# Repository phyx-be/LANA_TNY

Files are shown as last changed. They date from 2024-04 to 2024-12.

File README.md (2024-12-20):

# LANA TNY
## LANA
LANA is a small development board based around the [WCH CH32V203G6U6](https://www.wch-ic.com/products/CH32V203.html) RISC-V microcontroller. 

## CH32V203
Our initial development was made using the G8U6 variant of this microcontroller featuring more RAM, however by the time we finished the design the chip was no longer available in this small package with the larger RAM size. Therfore we settled for the CH32V203G6U6.
The CH32V203G6 has a single 32-bit RISC-V core, running up to 144MHz, with 1-cycle multiply, and hardware divide. Inside is **10KB** SRAM, **32KB** single-cycle Flash as well as an additional 'external XIP' **224KB** of Flash that can be used for program or data storage but is not as fast as the 32KB. There's also extras you expect: ADC, timers, USB device, UART, I2C, CAN, touch and SPI. 

## Where can I get one?
Currently you can get your hands on the LANA_TNY [in our Lectronz store](https://lectronz.com/products/lana-tny) or [through Adafruit](https://www.adafruit.com/product/6042).

## Programming

### Writing code
Various options are available.
- [Embeetle](https://embeetle.com/)
	- [Officially supported by Embeetle](https://embeetle.com/#supported-hardware/wch/boards/lana-tny-01)
- [Arduino core](https://github.com/openwch/arduino_core_ch32)
	- SPI and I²C Master support since version 1.0.2
- [Platform.io](https://github.com/Community-PIO-CH32V/platform-ch32v)
	- Requires your WCH-Link firmware to be updated to the latest version
- [CH32V003fun](https://github.com/cnlohr/ch32v003fun)
	- Experimental support for the CH32V203 at the time of writing
- [MounRiver Studio](https://www.mounriver.com/)
	- The official IDE supported by WCH, based on Eclipse.
- [WCH Toolchain for Mac](https://github.com/robinjanssens/WCH-Toolchain)
	- This toolchain has official support for LANA

### Loading code
The CH32V203 has an USB Bootloader which can be activated by holding down the button when plugging in the USB cable. Alternatively you could opt to use a [WCH-Link programmer and debugger](https://www.wch.cn/products/WCH-Link.html) to connect to the exposed SWD pins.

## TNY ?
TNY is our take on the [Adafruit QT Py](https://www.adafruit.com/category/595) and [Seeed studio XIAO](https://wiki.seeedstudio.com/Seeeduino-XIAO/) specifications but with added SMD pins for optional extra IO capabilities and a built in WS2811 compatible LED output.

## Pinout
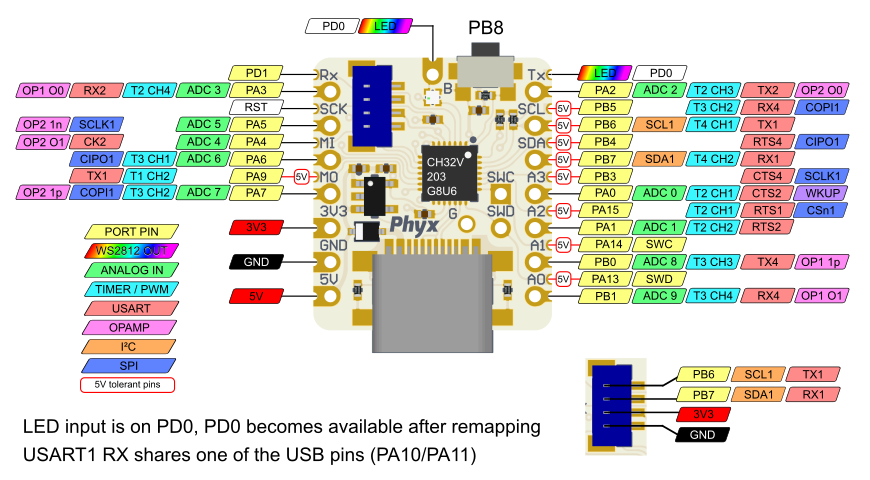
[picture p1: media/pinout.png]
LANA TNY 01 pinout


## LANA REV 01
LANA TNY 01 LED

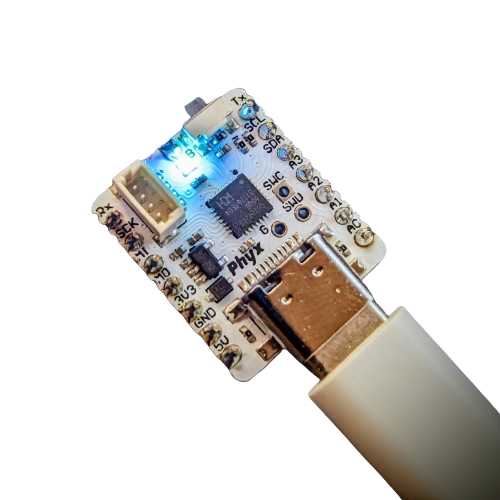
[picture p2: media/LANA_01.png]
LANA TNY 01


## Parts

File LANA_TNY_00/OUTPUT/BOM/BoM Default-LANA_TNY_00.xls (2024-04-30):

Bill of Materials |  |  | Lana Tny
Project: |  | LANA_TNY_00.PrjPcb
Revision: |  | 00
Variant: |  | Default
Creation Date: | 31/08/2023 | 09:10
Print Date: | 2023-09-01 | 14:35:48
Footprint | Comment | LibRef | Designator | Value | Description | Supplier 1 | Supplier PN 1 | Quantity | Quantity 500 | €500 | €1000
C0402 |  | CAP # 100nF 16V 0402 | C1, C2, C7 | 100nF 16V | CAP # 100nF 16V 0402 | LCSC | C392963 | 3 | 1500 | 1.05 | 1.8
C0402 |  | CAP # 1uF 10V 0402 | C3, C4 | 1uF 10V | CAP # 1uF 10V 0402 | LCSC | C380293 | 2 | 1000 | 1.4 | 2.8
LED_1010_WS2812B | WS2812 based digital RGB LED 1010 package | LED # RGB XL-1010RGBC-WS2812B | D1 | XL-1010RGBC-WS2812B | LED # RGB XL-1010RGBC-WS2812B | LCSC | C5349953 | 1 | 500 | 18.4 | 32.9
SOD-323_AC | CUS10S30 Schottky Power Rectifier, 1A, 30V | Schottky # CUS10S30 | D2 | CUS10S30,H3F | Schottky # CUS10S30 | LCSC | C146335 | 1 | 500 | 12.35 | 24.7
XUNPU-TYPEC-304S-ACP16 | USB 2.0 C Reversible Receptacle Horizontal full SMD | USB # C 2.0 RCPT TYPEC-304S-ACP16 | J1 | TYPEC-304S-ACP16 | USB # C 2.0 RCPT TYPEC-304S-ACP16 | LCSC | C5187472 | 1 | 500 | 21.75 | 37.4
WE_665304124022 | Header 1.0mm Shrouded 4 | HDR # SHR 1.0mm 4way - 665304124022 | P3 | 665304124022 | HDR # SHR 1.0mm 4way - 665304124022 | LCSC | C7433440 | 1 | 500 | 7.5 | 14.6
R0402 |  | RES # 5K1 0402 | R1, R2, R3, R4, R5 | 5K1 | RES # 5K1 0402 | LCSC | C274895 | 5 | 2500 | 1.5 | 2.5
SHOU_HAN_TS24CA | TS24CA RA Tactile Switch 12V 50mA | SW # TACT RA TS24CA | SW2 | TS24CA | SW # TACT RA TS24CA | LCSC | C393942 | 1 | 500 | 7.65 | 13
QFN_28_4.0x4.0_P0.4 | WCH CH32V203G8U6 QFN28 RISC-V 32-bit MCU, 64KB Flash, 20KB RAM, USB, CAN | RISCV # CH32V203G8U6 | U1 | CH32V203G8U6 | RISCV # CH32V203G8U6 | LCSC | C5187530 | 1 | 500 | 173.05 | 338.8
SOT23-5 | 3V3 LDO 300mA 150mV | LDO # 3V3 300mA RT9078-33GJ5 | U2 | RT9078-33GJ5 | LDO # 3V3 300mA RT9078-33GJ5 | LCSC | C110427 | 1 | 500 | 27.05 | 54.1
 |  |  |  |  |  |  |  | 17 |  | €271.70 | €522.60
Approved |  | Notes
 |  |  |  |  |  |  |  |  |  | €0.5434 | €0.5226

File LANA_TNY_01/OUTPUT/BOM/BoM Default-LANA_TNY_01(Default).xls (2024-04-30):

Bill of Materials |  |  | Lana Tny
Project: |  | LANA_TNY_01.PrjPcb
Revision: |  | 01
Variant: |  | Default
Creation Date: | 12/11/2023 | 20:50
Print Date: | 2024-04-12 | 10:24:27
Footprint | Comment | LibRef | Designator | Value | Description | Supplier 1 | Supplier Part Number 1 | Supplier 2 | Supplier Part Number 2 | Supplier 3 | Supplier Part Number 3 | Quantity
C0402 |  | CAP # 100nF 16V 0402 | C1, C2, C7 | 100nF 16V | CAP # 100nF 16V 0402 | Farnell | 1758896 | LCSC | C392963 | Generic | 100nF 16V 0402 X7R | 3
C0402 |  | CAP # 1uF 10V 0402 | C3, C4 | 1uF 10V | CAP # 1uF 10V 0402 | LCSC | C380293 |  |  | Generic | 1uF 10V 0402 X5R | 2
LED_1010_WS2812B | WS2812 based digital RGB LED 1010 package | LED # RGB XL-1010RGBC-WS2812B | D1 | XL-1010RGBC-WS2812B | LED # RGB XL-1010RGBC-WS2812B | LCSC | C5349953 |  |  |  |  | 1
SOD-323_AC | CUS10S30 Schottky Power Rectifier, 1A, 30V | Schottky # CUS10S30 | D2 | CUS10S30,H3F | Schottky # CUS10S30 | LCSC | C146335 |  |  |  |  | 1
XUNPU-TYPEC-304S-ACP16 | USB 2.0 C Reversible Receptacle Horizontal full SMD | USB # C 2.0 RCPT TYPEC-304S-ACP16 | J1 | TYPEC-304S-ACP16 | USB # C 2.0 RCPT TYPEC-304S-ACP16 | LCSC | C5187472 | LCSC | C2927040 | LCSC | C5156603 | 1
WE_665304124022 | Header 1.0mm Shrouded 4 | HDR # SHR 1.0mm 4way - 665304124022 | P3 | 665304124022 | HDR # SHR 1.0mm 4way - 665304124022 | Wurth | 665304124022 | Mouser | 710-665304124022 |  |  | 1
R0402 |  | RES # 5K1 0402 | R1, R2, R3, R4, R5 | 5K1 | RES # 5K1 0402 | LCSC | C274895 |  |  | Generic | 5K1 1% 0402 | 5
SHOU_HAN_TS24CA | TS24CA RA Tactile Switch 12V 50mA | SW # TACT RA TS24CA | SW2 | TS24CA | SW # TACT RA TS24CA | LCSC | C393942 |  |  |  |  | 1
QFN_28_4.0x4.0_P0.4 | WCH CH32V203G8U6 QFN28 RISC-V 32-bit MCU, 64KB Flash, 20KB RAM, USB, CAN | RISCV # CH32V203G8U6 | U1 | CH32V203G8U6 | RISCV # CH32V203G8U6 | LCSC | C5187530 |  |  |  |  | 1
SOT23-5 | 3V3 LDO 300mA 150mV | LDO # 3V3 300mA RT9078-33GJ5 | U2 | RT9078-33GJ5 | LDO # 3V3 300mA RT9078-33GJ5 | LCSC | C110427 |  |  |  |  | 1
 |  |  |  |  |  |  |  |  |  |  |  | 17
Approved |  | Notes

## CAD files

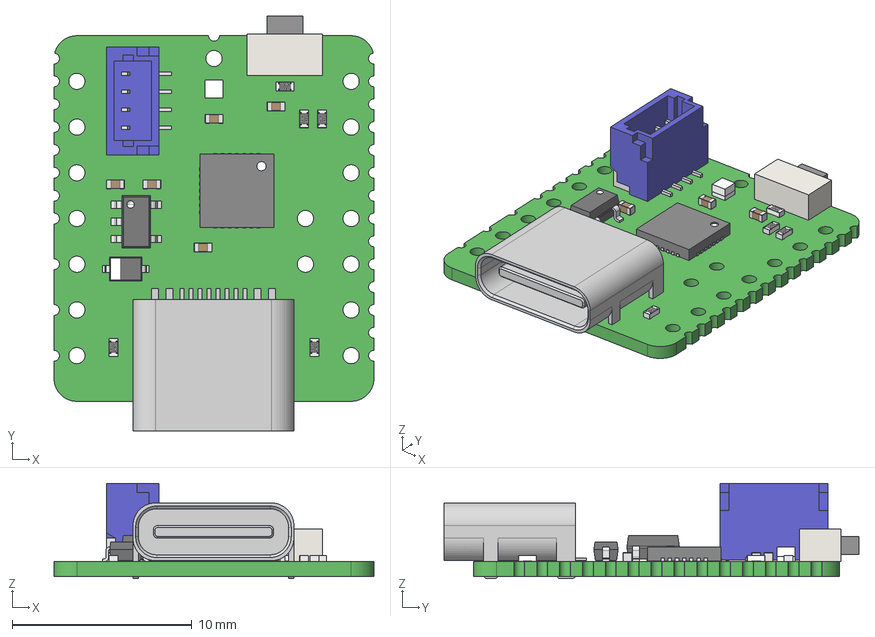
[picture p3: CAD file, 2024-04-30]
LANA_TNY_00/LANA_TNY_00.step
17.8 x 23.0 x 5.30 mm
R0402 x 5
BM04B-SRSS-TB
C0402 x 5
Extruded x 5
User Library-SOT23-5-2
User Library-SOD323-1
Thermal Shape
HRO TYPE-C-31-M-12

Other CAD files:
LANA_TNY_01/LANA_TNY_01.step

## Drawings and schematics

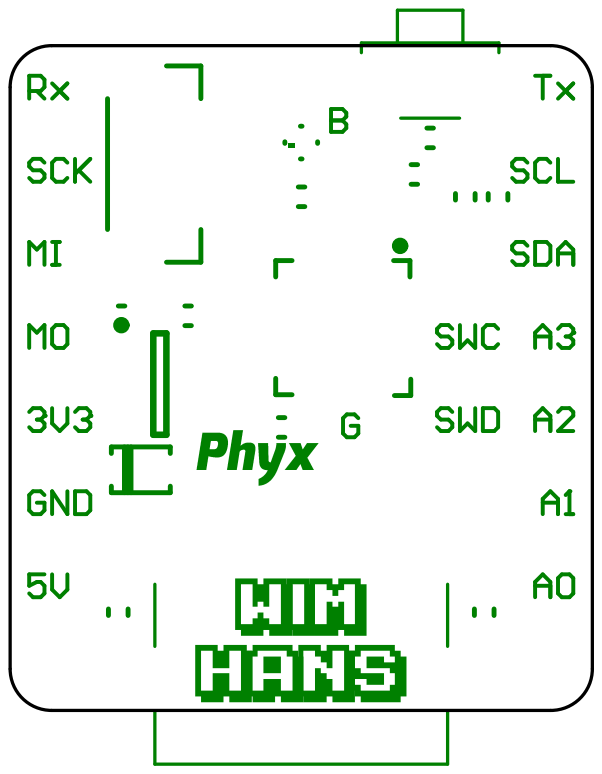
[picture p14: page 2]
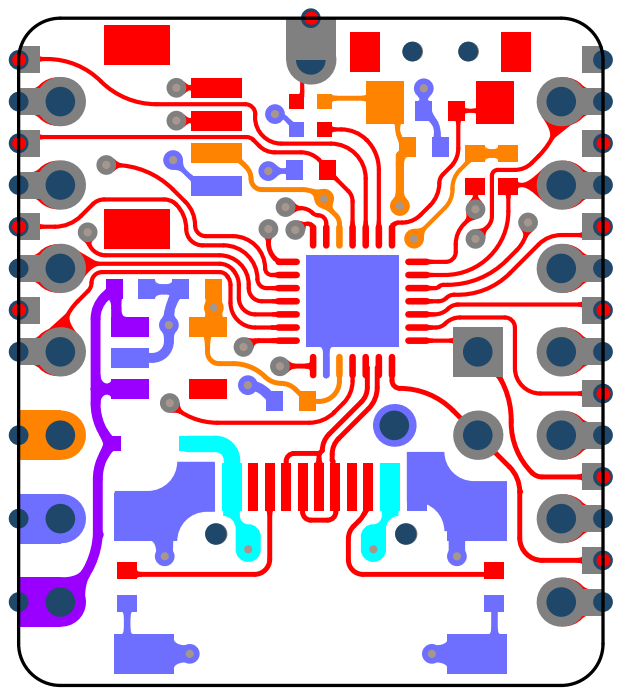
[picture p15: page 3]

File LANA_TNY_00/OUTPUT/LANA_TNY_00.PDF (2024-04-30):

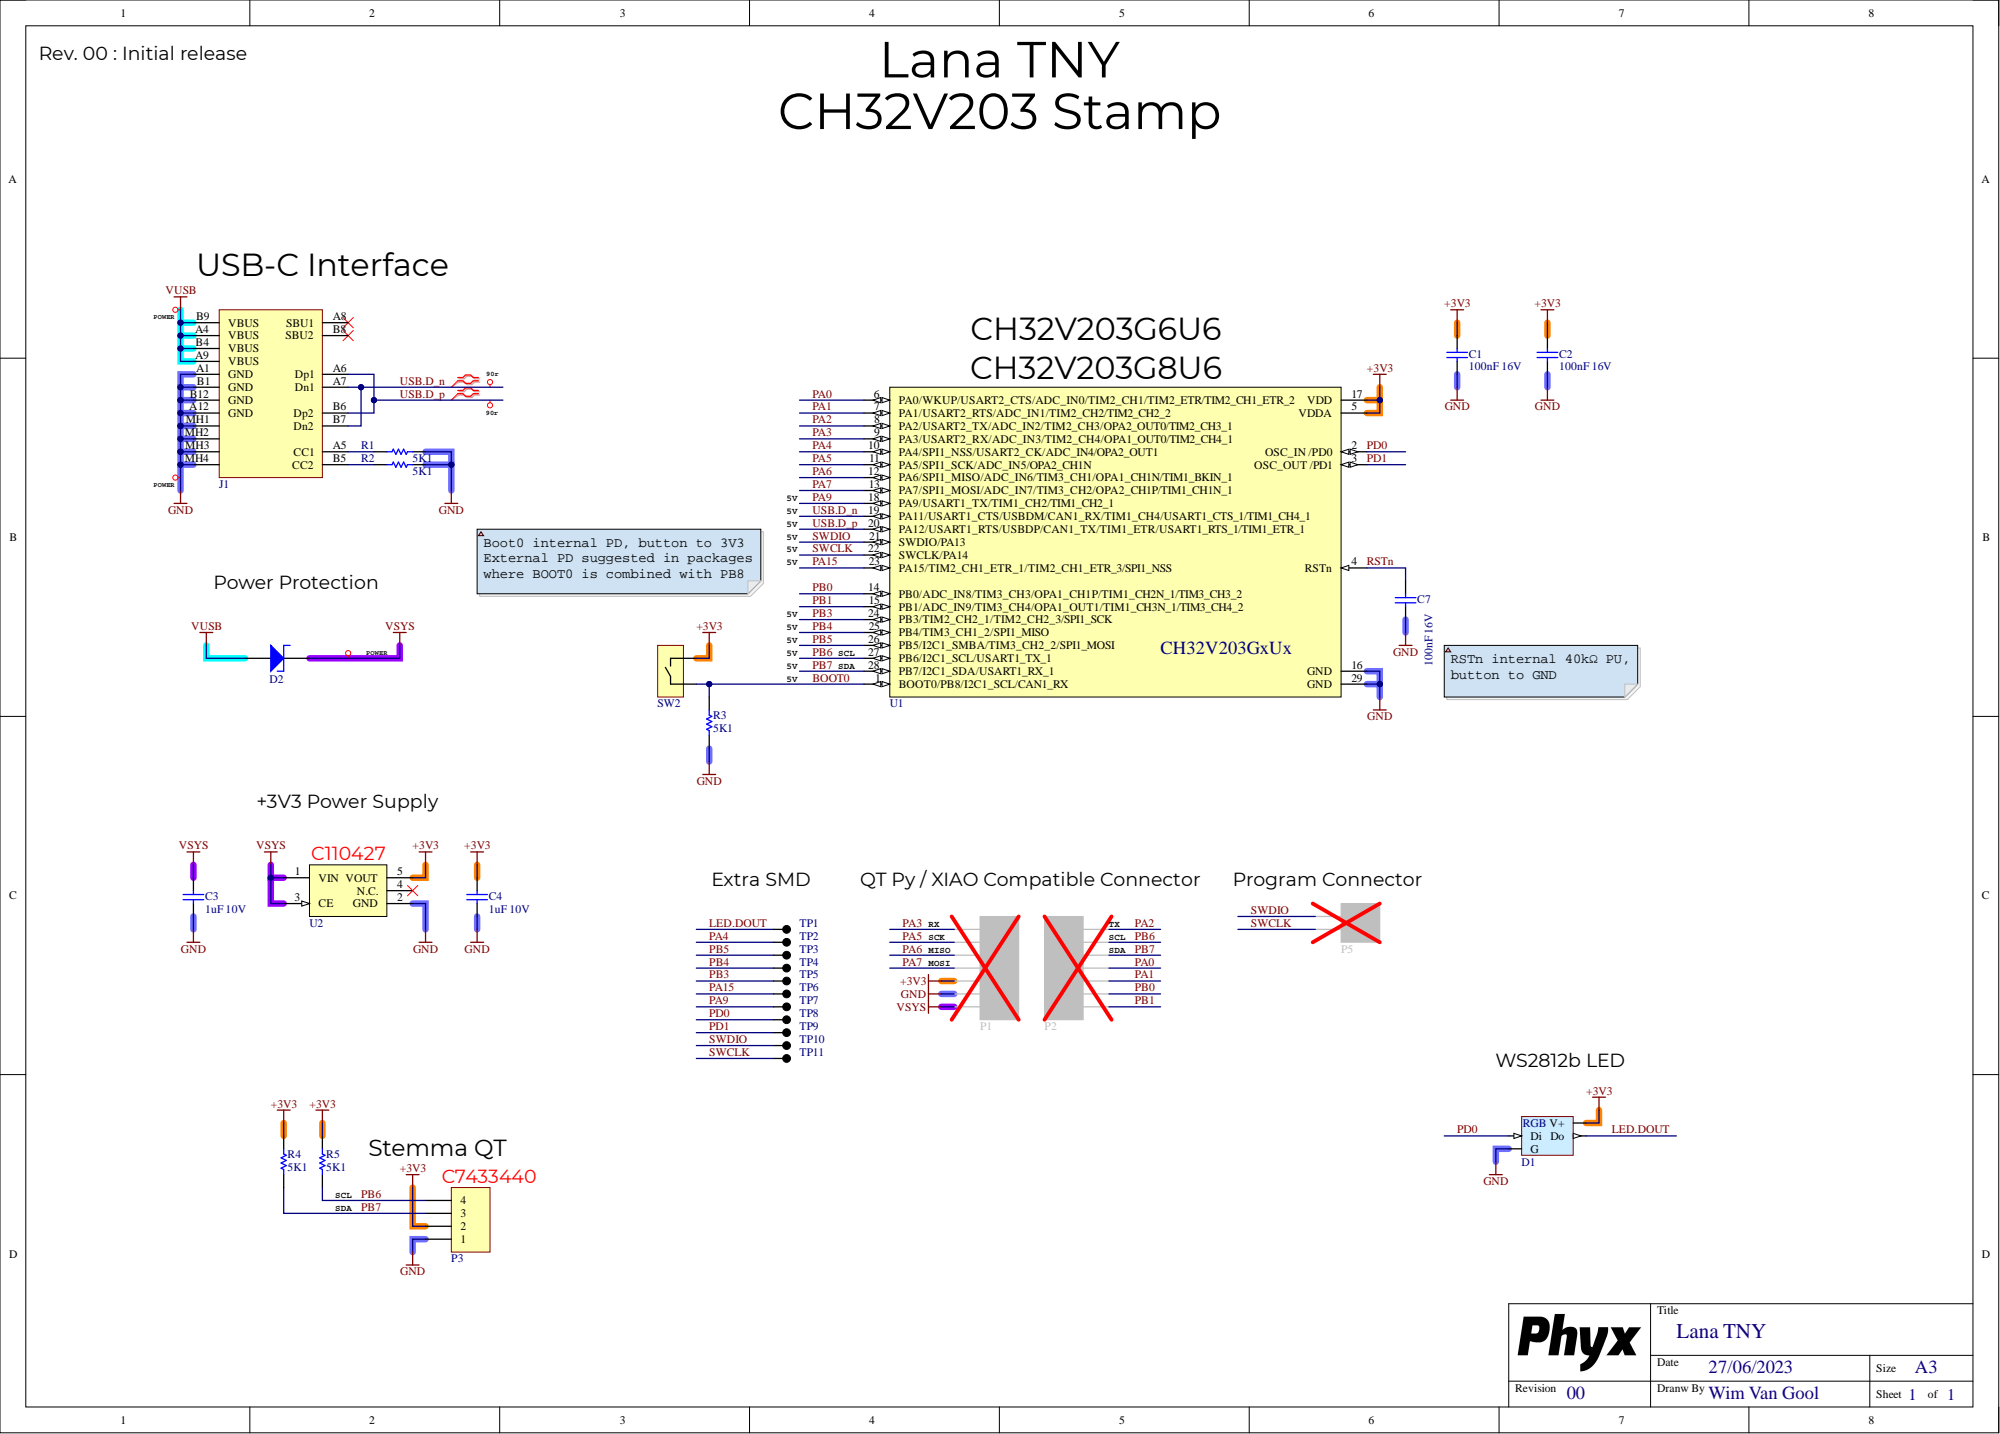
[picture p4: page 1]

Lana TNY Rev. 00 : Initial release

USB-C Interface USB.D_n USB.D_p

Boot0 internal PD, button to 3V3
External PD suggested in packages

where BOOT0 is combined with PB8

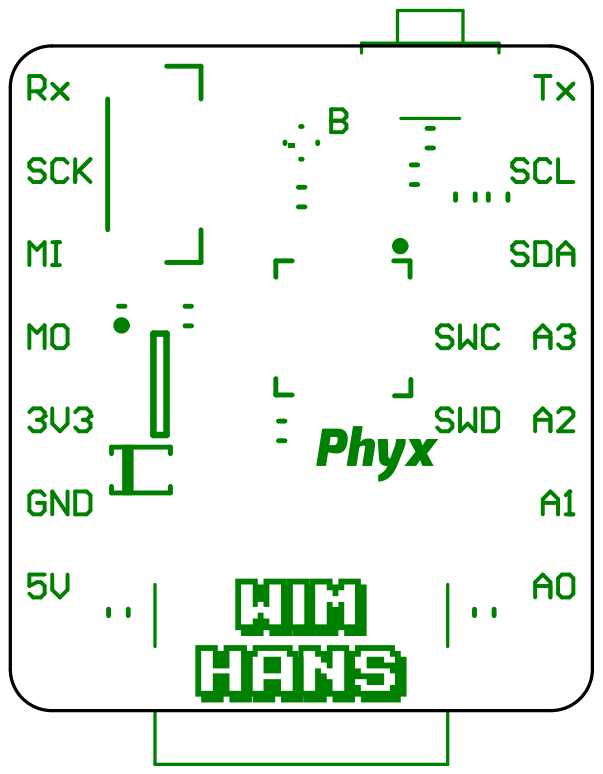
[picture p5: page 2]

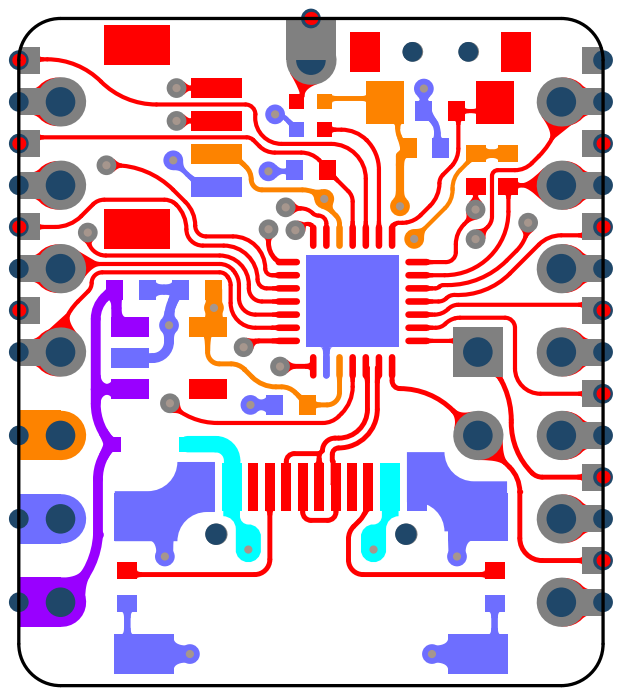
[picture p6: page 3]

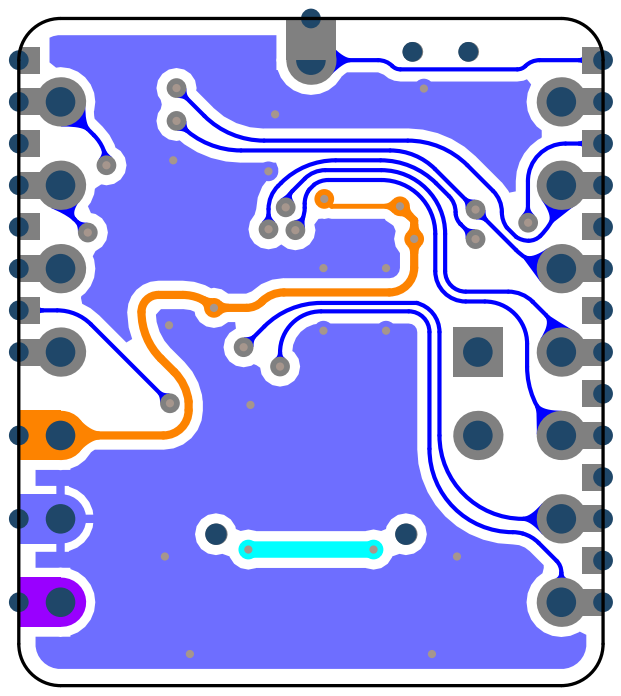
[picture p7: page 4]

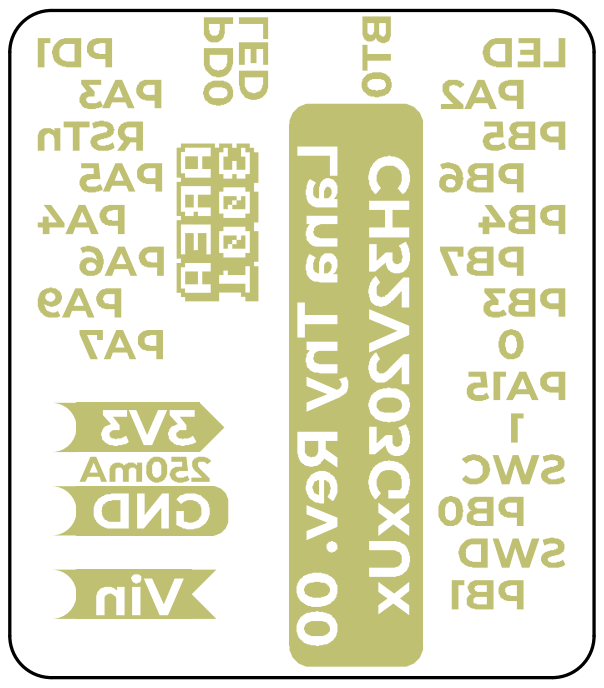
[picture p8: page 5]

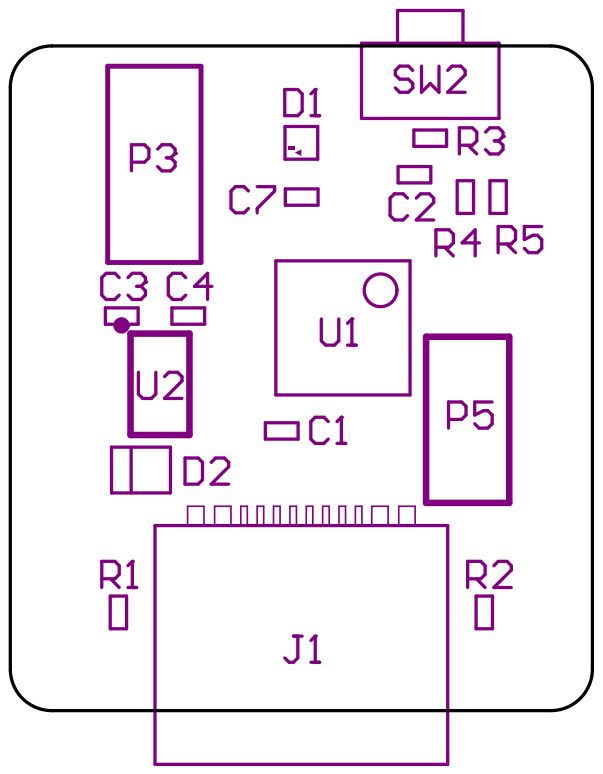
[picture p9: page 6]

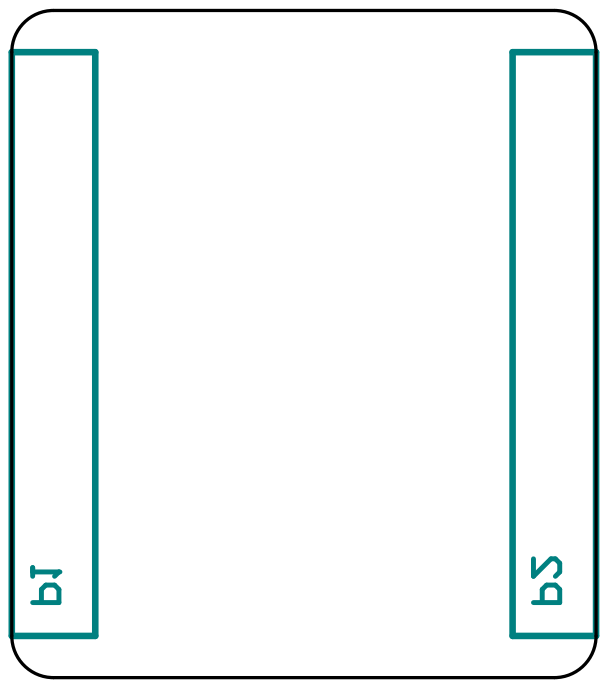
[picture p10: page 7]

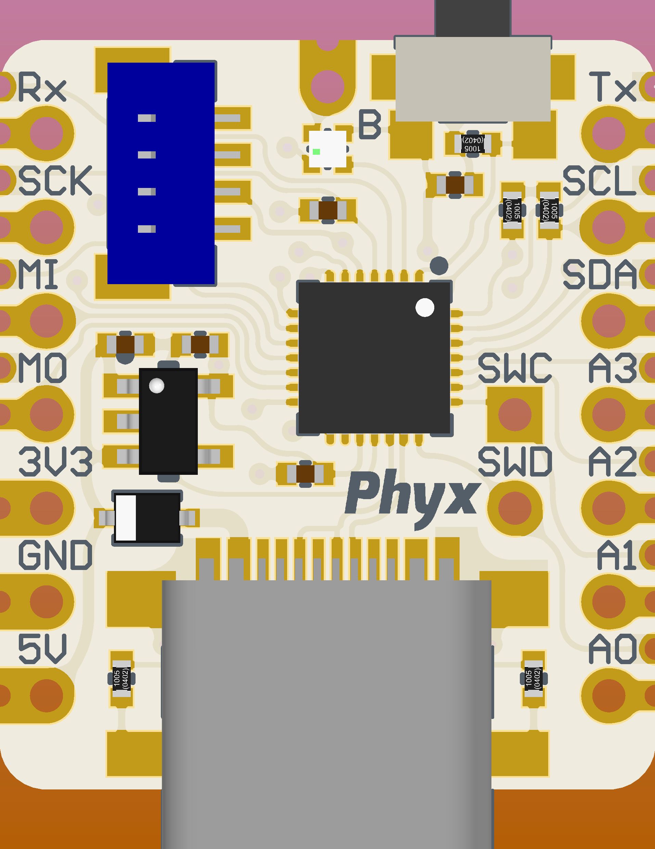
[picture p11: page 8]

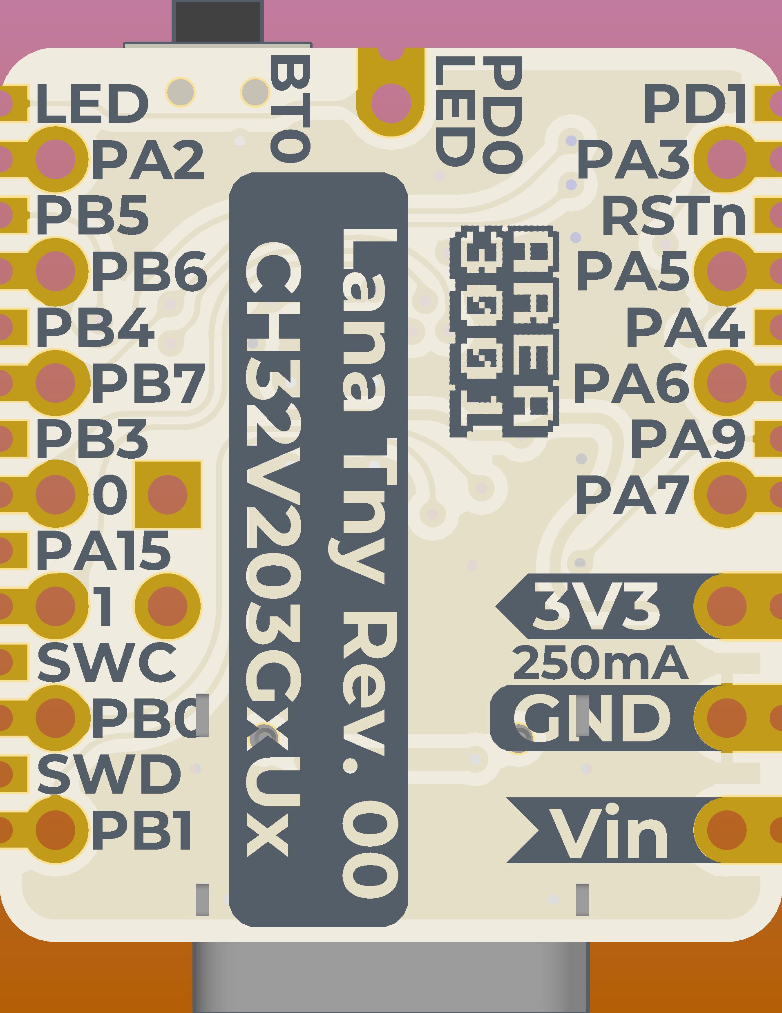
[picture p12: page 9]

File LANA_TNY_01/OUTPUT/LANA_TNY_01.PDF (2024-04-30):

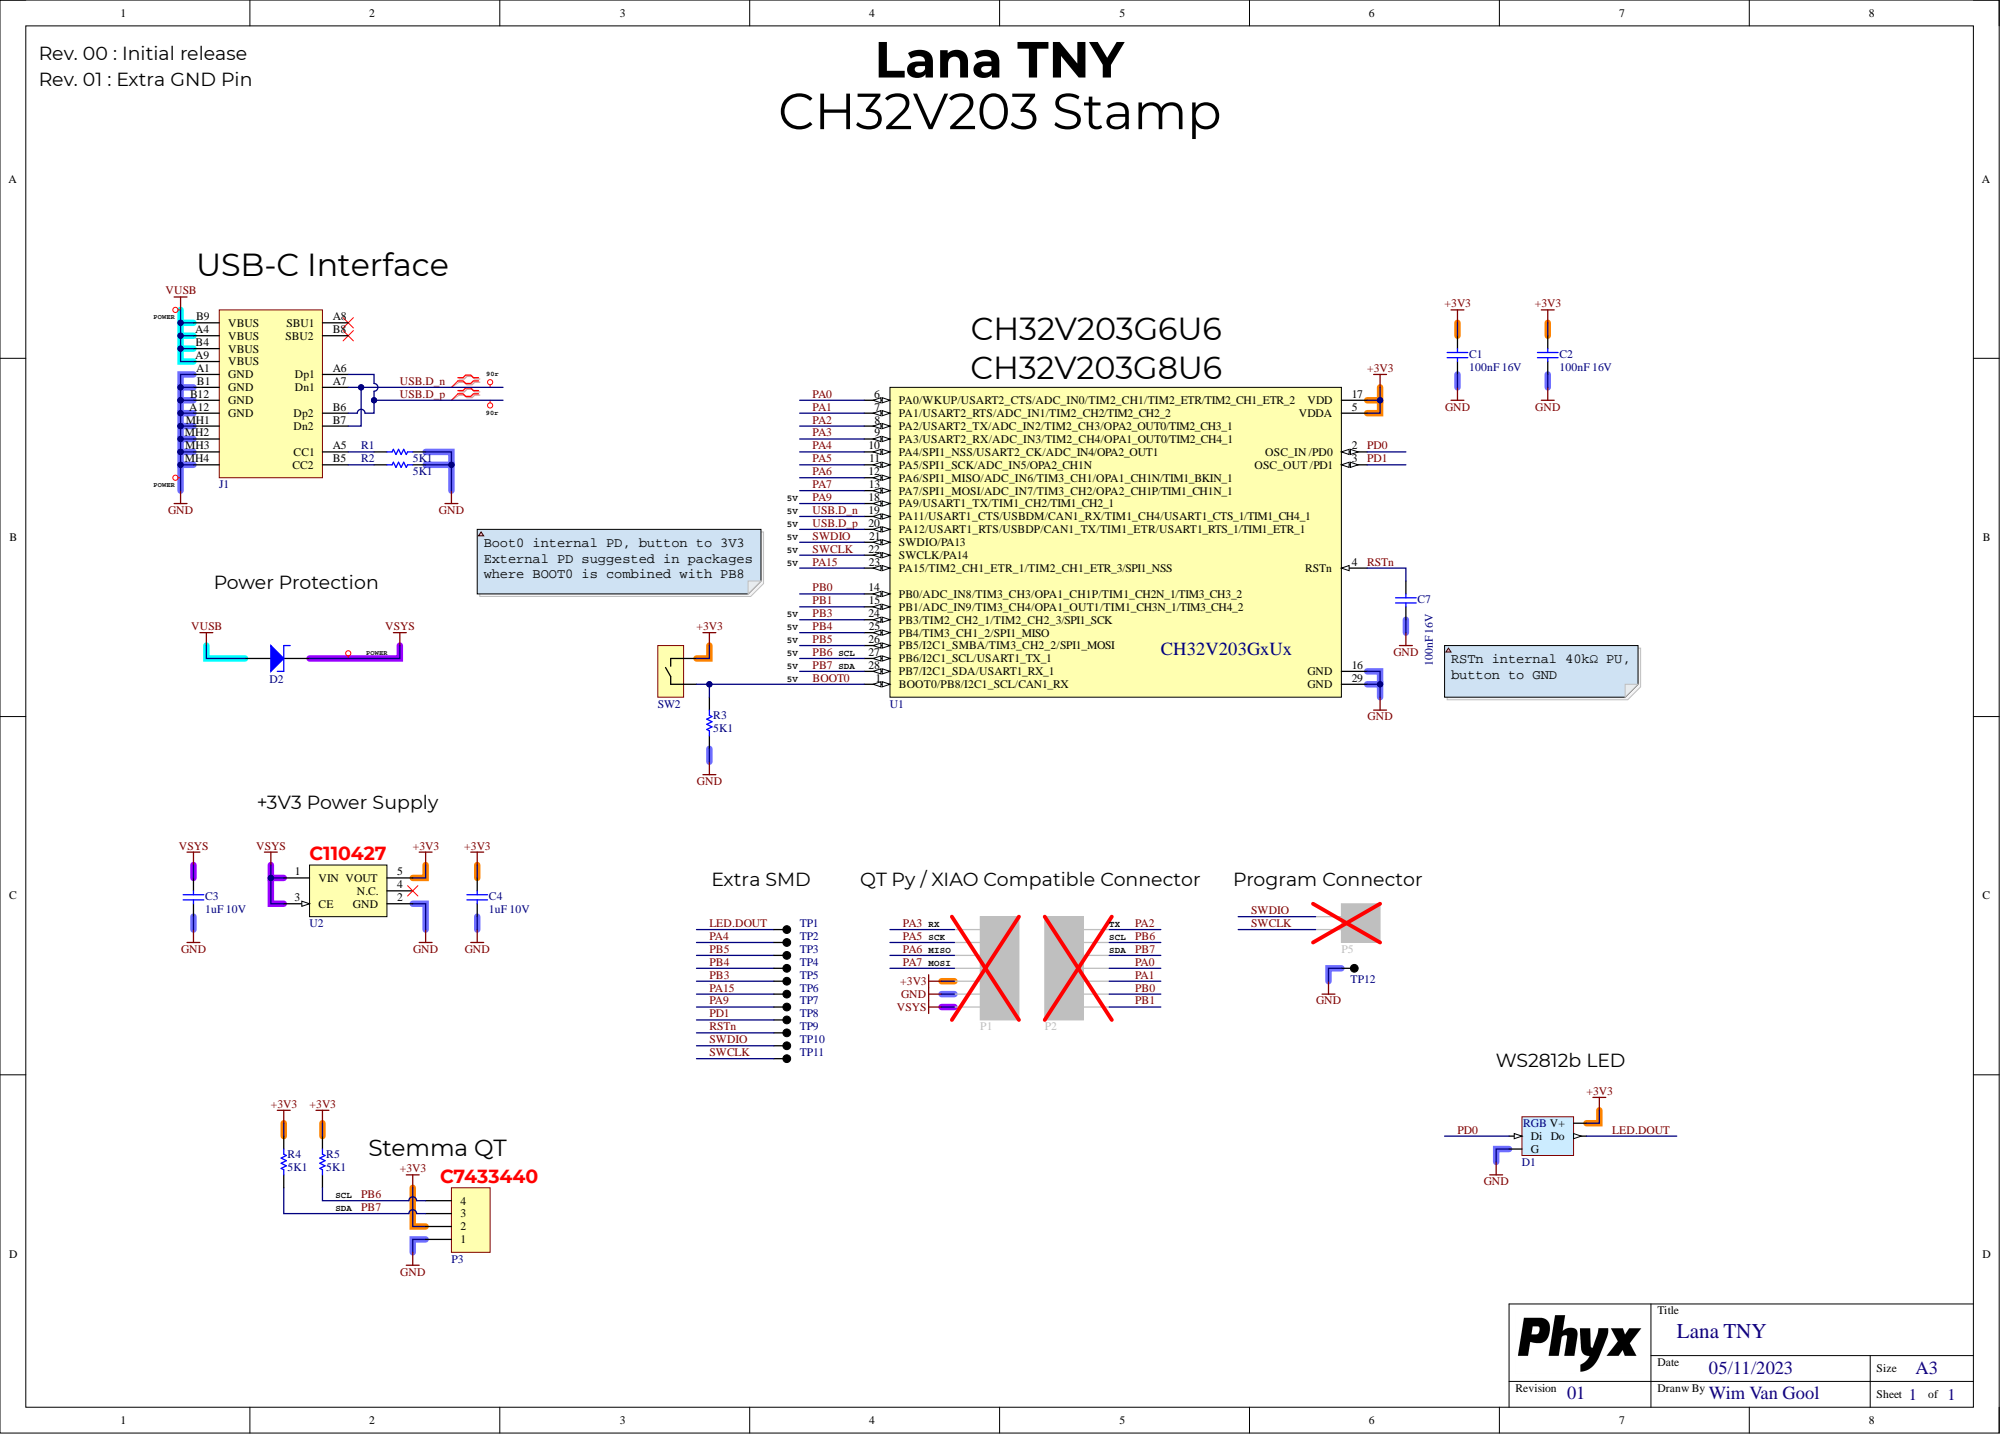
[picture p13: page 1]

Lana TNY Rev. 00 : Initial release
Rev. 01 :

USB-C Interface USB.D_n USB.D_p

Boot0 internal PD, button to 3V3
External PD suggested in packages

where BOOT0 is combined with PB8
